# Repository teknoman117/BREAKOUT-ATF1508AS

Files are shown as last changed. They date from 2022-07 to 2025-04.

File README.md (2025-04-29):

# BREAKOUT-ATF1508AS

A breakout board for the PLCC84 version of the ATF1504AS or ATF1508AS. Allows for usage in a breadboard environment.

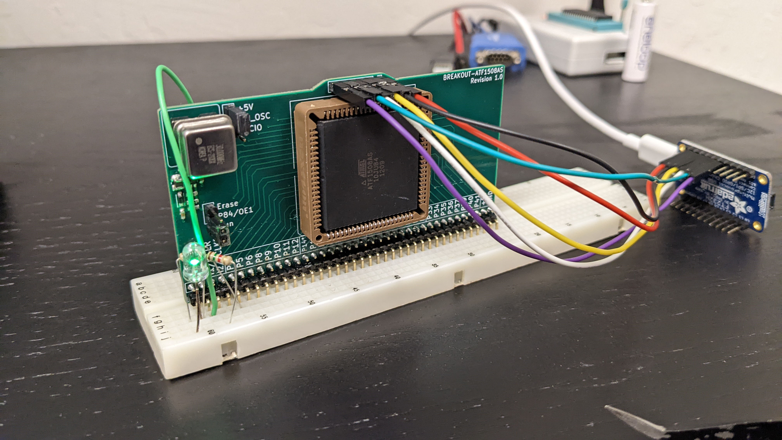
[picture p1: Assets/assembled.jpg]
Assembled


### Example Project

See Example

### Dual Voltage Rails

The PLCC84 variants of the ATF1504AS and ATF1504AS provide two voltage rails - VCCINT and VCCIO. VCCINT is the CPLD core voltage and is required to be at 5V. VCCIO is the external IO voltage and can be either 3.3V (3.0V to 3.6V) or 5V.

### Oscillator

Socket X1 is for a 3.3V or 5V TTL oscillator in the 4 lead DIP-8 form factor. The enable pin is left electrically unconnected, which is enabled for the majority of TTL oscillators. 

The oscillator output is connected to I83/GCLK1. If an external clock is provided on I83/GCLK1 through the breakout headers, the oscillator must be removed.

Jumper JP1 selects the source voltage of the oscillator. Position 1-2 connects the oscillator to the VCCIO rail and Position 2-3 connects to the VCCINT (5V) rail.

### Programming

In the event that JTAG has been disabled on the CPLD, a 12V boost regulator is provided to force the CPLD into JTAG mode.

Jumper JP2 selects the function of the I84/OE1 pin. Position 1-2 is normal operation, with the pin connected to the breakout headers along the bottom of the board. Position 2-3 is for erase. This disconnects the pin from the breakout headers and instead connects it to 12V through current limiting resistor R3 (2.2 kOhm by default).

Programming can be achieved with an official programmer or a FT232H and OpenOCD. See FT232H Instructions

Please note that JTAG Header J1 is not isolated from the breakout headers. If the design uses P14 (TDI), P23 (TMS), P62 (TCK), or P71 (TDO), the breakout board may need to be removed from the circuit prior to programming.

### Errata

The I2/GCLK2 label on the breakout headers should be I2/GCLK2/OE2.

### License

CC-BY-SA 4.0

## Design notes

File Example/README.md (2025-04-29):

Shift Register Example
=====================

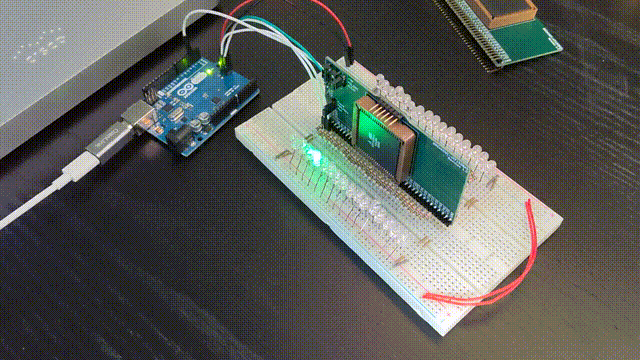
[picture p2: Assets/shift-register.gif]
demo


Connections
-----------

| Arduino | CPLD |
| --- | ---- |
| 2 |  83  |
| RST |  1 |
| 11 (MOSI) |  84  |
| 13 (SCK)  |  2 |

Instructions
------------
Run "build-pld.bash" to compile the HDL image for the ATF1508AS, assuming wincupl is installed the C drive in the Wine Prefix "$HOME/.wine32"

Build and run "shift-register.ino" on an attached Arduino Uno

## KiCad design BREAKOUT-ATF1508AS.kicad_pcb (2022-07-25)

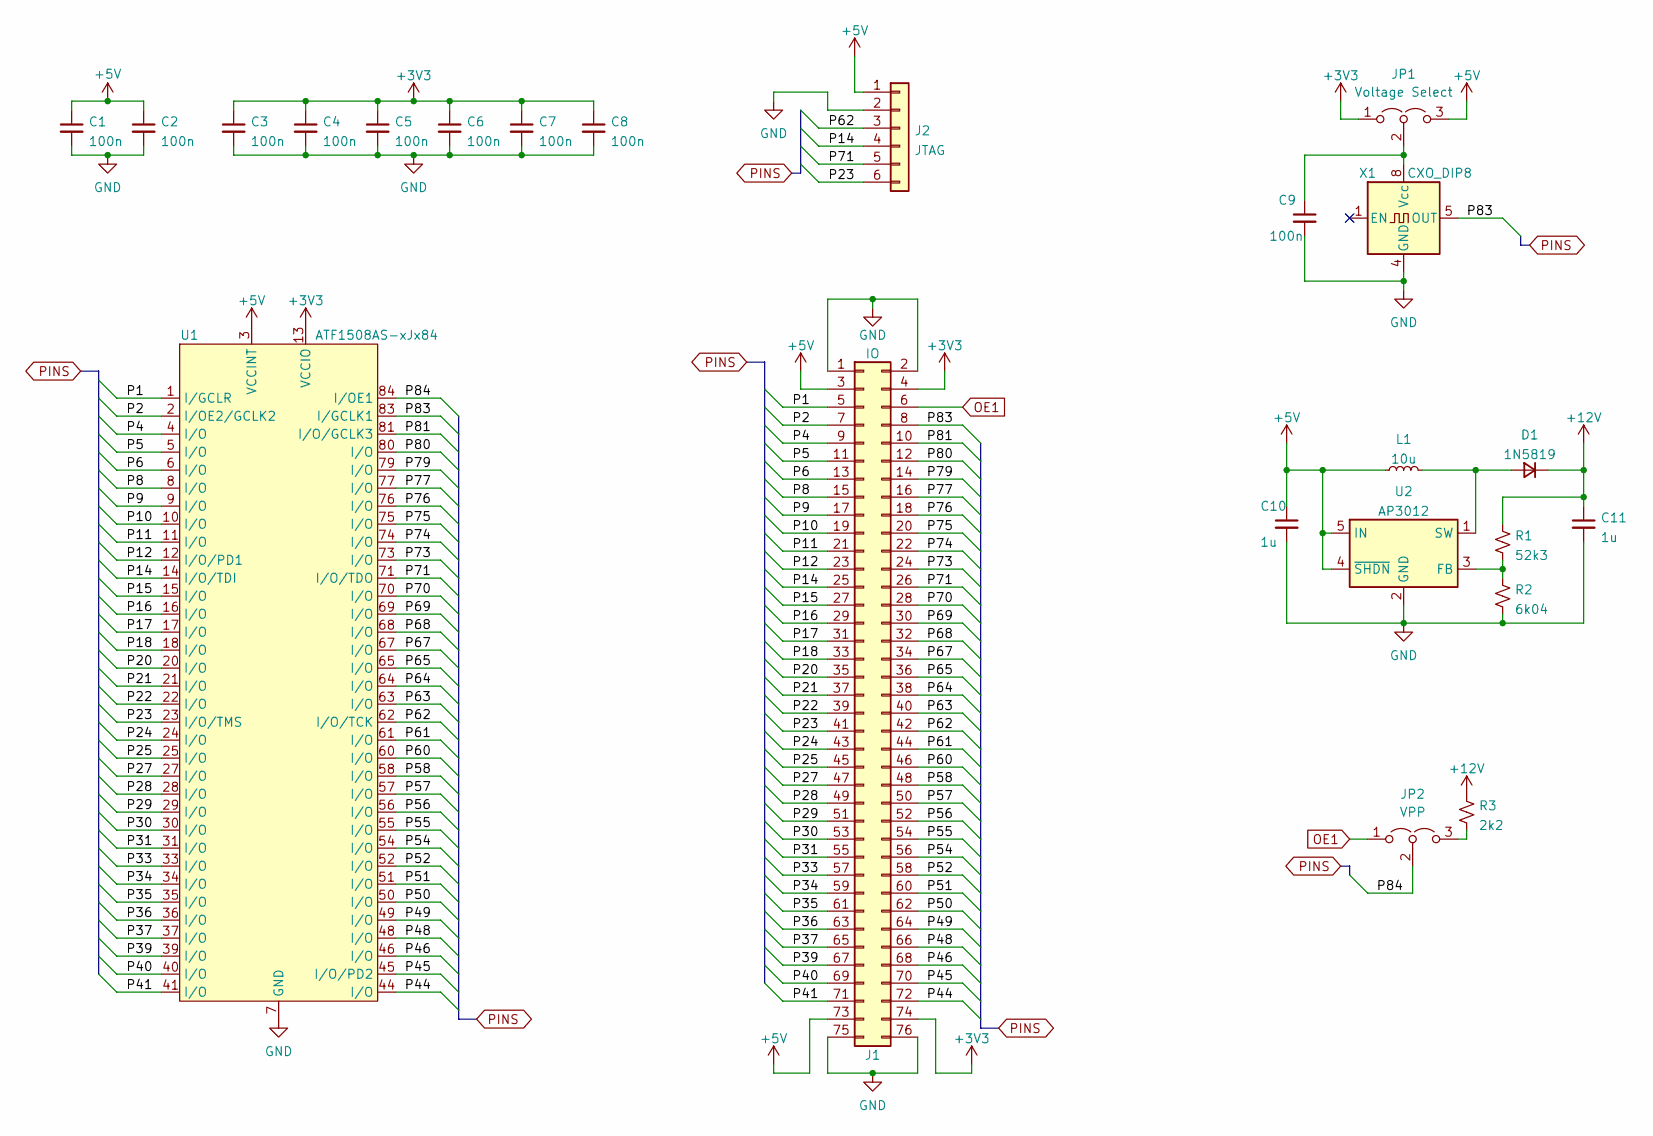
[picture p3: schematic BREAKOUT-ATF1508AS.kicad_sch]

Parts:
C1, C2, C3, C4, C5, C6, C7, C8, C9: 100n; C_0603_1608Metric_Pad1.08x0.95mm_HandSolder
C10, C11: 1u; C_0603_1608Metric_Pad1.08x0.95mm_HandSolder
D1: 1N5819; D_SOD-323_HandSoldering
J1: IO; PinHeader_2x38_P2.54mm_Vertical
J2: JTAG; PinHeader_1x06_P2.54mm_Vertical
JP1: Voltage Select; PinHeader_1x03_P2.54mm_Vertical
JP2: VPP; PinHeader_1x03_P2.54mm_Vertical
L1: 10u; L_1008_2520Metric_Pad1.43x2.20mm_HandSolder
R1: 52k3; R_0603_1608Metric_Pad0.98x0.95mm_HandSolder
R2: 6k04; R_0603_1608Metric_Pad0.98x0.95mm_HandSolder
R3: 2k2; R_0603_1608Metric_Pad0.98x0.95mm_HandSolder
U1: ATF1508AS-xJx84; PLCC-84_THT-Socket
U2: AP3012; SOT-23-5
X1: CXO_DIP8; Oscillator_DIP-8

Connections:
+3V3: C3.1, C4.1, C5.1, C6.1, C7.1, C8.1, J1.4, J1.74, JP1.1 (A), U1.13 (VCCIO), U1.26 (VCCIO), U1.38 (VCCIO), U1.53 (VCCIO), U1.66 (VCCIO), U1.78 (VCCIO)
+5V: C1.1, C2.1, C10.1, J1.3, J1.73, J2.1, JP1.3 (B), L1.1, U1.3 (VCCINT), U1.43 (VCCINT), U2.4 (~SHDN), U2.5 (IN)
+12V: C11.1, D1.1 (K), R1.1, R3.1
/P1: J1.5, U1.1 (I/GCLR)
/P2: J1.7, U1.2 (I/OE2/GCLK2)
/P4: J1.9, U1.4 (I/O)
/P5: J1.11, U1.5 (I/O)
/P6: J1.13, U1.6 (I/O)
/P8: J1.15, U1.8 (I/O)
/P9: J1.17, U1.9 (I/O)
/P10: J1.19, U1.10 (I/O)
/P11: J1.21, U1.11 (I/O)
/P12: J1.23, U1.12 (I/O/PD1)
/P14: J1.25, J2.4, U1.14 (I/O/TDI)
/P15: J1.27, U1.15 (I/O)
/P16: J1.29, U1.16 (I/O)
/P17: J1.31, U1.17 (I/O)
/P18: J1.33, U1.18 (I/O)
/P20: J1.35, U1.20 (I/O)
/P21: J1.37, U1.21 (I/O)
/P22: J1.39, U1.22 (I/O)
/P23: J1.41, J2.6, U1.23 (I/O/TMS)
/P24: J1.43, U1.24 (I/O)
/P25: J1.45, U1.25 (I/O)
/P27: J1.47, U1.27 (I/O)
/P28: J1.49, U1.28 (I/O)
/P29: J1.51, U1.29 (I/O)
/P30: J1.53, U1.30 (I/O)
/P31: J1.55, U1.31 (I/O)
/P33: J1.57, U1.33 (I/O)
/P34: J1.59, U1.34 (I/O)
/P35: J1.61, U1.35 (I/O)
/P36: J1.63, U1.36 (I/O)
/P37: J1.65, U1.37 (I/O)
/P39: J1.67, U1.39 (I/O)
/P40: J1.69, U1.40 (I/O)
/P41: J1.71, U1.41 (I/O)
/P44: J1.72, U1.44 (I/O)
/P45: J1.70, U1.45 (I/O/PD2)
/P46: J1.68, U1.46 (I/O)
/P48: J1.66, U1.48 (I/O)
/P49: J1.64, U1.49 (I/O)
/P50: J1.62, U1.50 (I/O)
/P51: J1.60, U1.51 (I/O)
/P52: J1.58, U1.52 (I/O)
/P54: J1.56, U1.54 (I/O)
/P55: J1.54, U1.55 (I/O)
/P56: J1.52, U1.56 (I/O)
/P57: J1.50, U1.57 (I/O)
/P58: J1.48, U1.58 (I/O)
/P60: J1.46, U1.60 (I/O)
/P61: J1.44, U1.61 (I/O)
/P62: J1.42, J2.3, U1.62 (I/O/TCK)
/P63: J1.40, U1.63 (I/O)
/P64: J1.38, U1.64 (I/O)
/P65: J1.36, U1.65 (I/O)
/P67: J1.34, U1.67 (I/O)
/P68: J1.32, U1.68 (I/O)
/P69: J1.30, U1.69 (I/O)
/P70: J1.28, U1.70 (I/O)
/P71: J1.26, J2.5, U1.71 (I/O/TDO)
/P73: J1.24, U1.73 (I/O)
/P74: J1.22, U1.74 (I/O)
/P75: J1.20, U1.75 (I/O)
/P76: J1.18, U1.76 (I/O)
/P77: J1.16, U1.77 (I/O)
/P79: J1.14, U1.79 (I/O)
/P80: J1.12, U1.80 (I/O)
/P81: J1.10, U1.81 (I/O/GCLK3)
/P83: J1.8, U1.83 (I/GCLK1), X1.5 (OUT)
/P84: JP2.2 (C), U1.84 (I/OE1)
GND: C1.2, C2.2, C3.2, C4.2, C5.2, C6.2, C7.2, C8.2, C9.2, C10.2, C11.2, J1.1, J1.2, J1.75, J1.76, J2.2, R2.2, U1.7 (GND), U1.19 (GND), U1.32 (GND), U1.42 (GND), U1.47 (GND), U1.59 (GND), U1.72 (GND), U1.82 (GND), U2.2 (GND), X1.4 (GND)
unnamed: C9.1, JP1.2 (C), X1.8 (Vcc)
unnamed: D1.2 (A), L1.2, U2.1 (SW)
unnamed: JP2.3 (B), R3.2
unnamed: R1.2, R2.1, U2.3 (FB)
OE1: J1.6, JP2.1 (A)

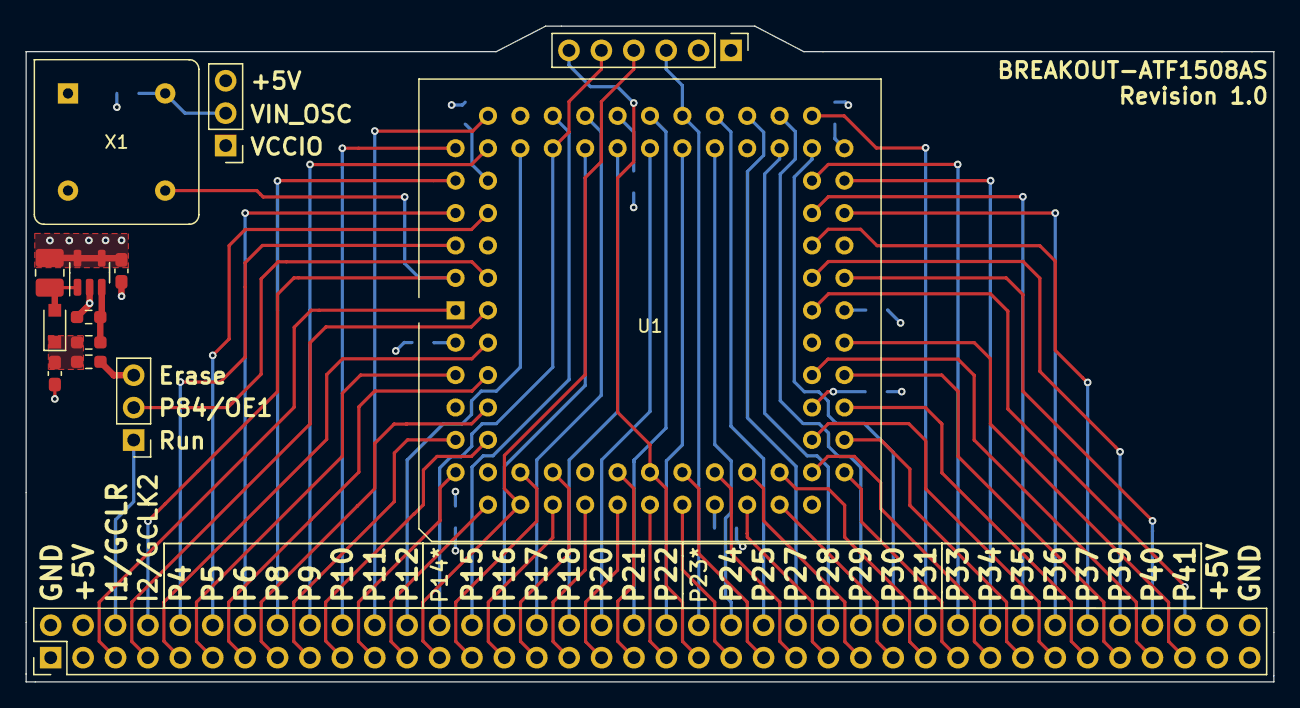
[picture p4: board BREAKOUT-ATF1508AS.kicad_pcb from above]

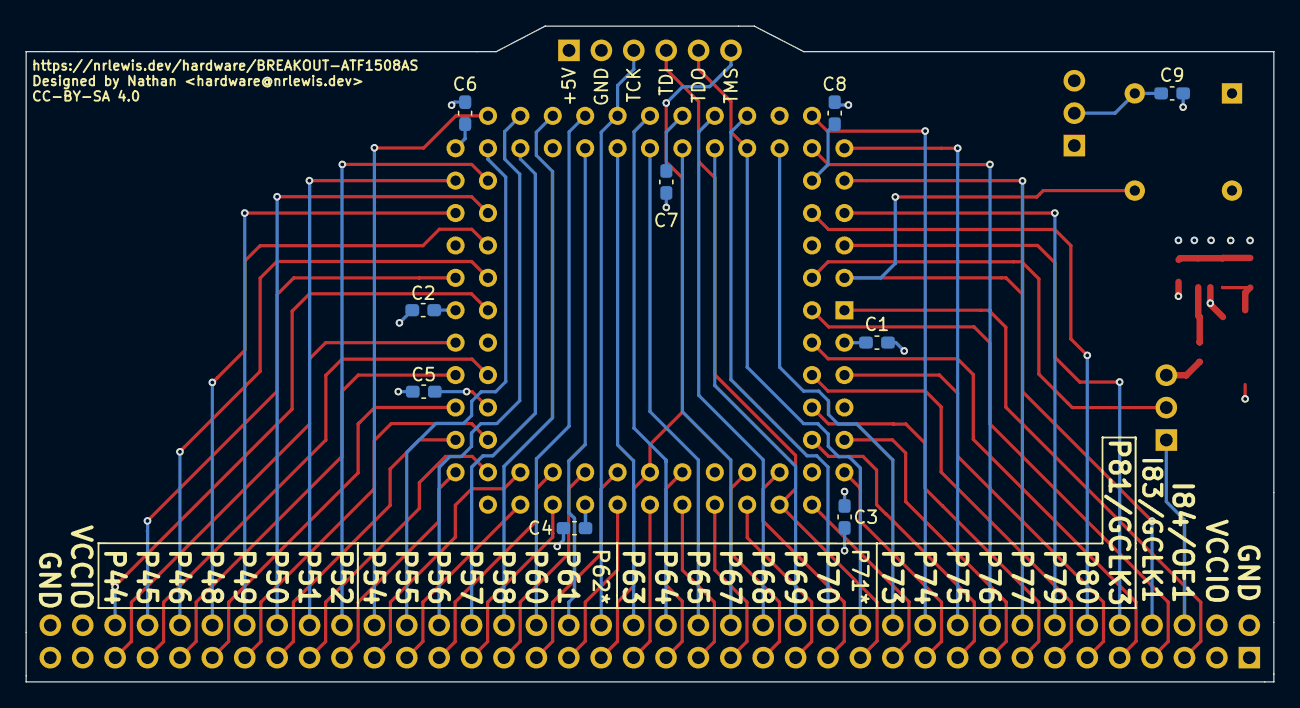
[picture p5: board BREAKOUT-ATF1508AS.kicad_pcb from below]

Board: 4 copper layers, 97.8 x 51.4 mm, 23 parts (9 on the bottom side), 77 nets.

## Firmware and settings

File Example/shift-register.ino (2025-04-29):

#include <SPI.h>

uint8_t t = 0;

void setup() {
  pinMode(2, OUTPUT);
  digitalWrite(2, LOW);

  SPI.begin();
  SPI.setBitOrder(LSBFIRST);
  SPI.setClockDivider(SPI_CLOCK_DIV4);
  Serial.begin(115200);
}

void loop() {
  uint64_t v = ~(3ULL << t);
  t = (t+1) % 64;

  SPI.transfer(&v, sizeof v);
  digitalWrite(2, HIGH);
  digitalWrite(2, LOW);
  delay(20);
}
